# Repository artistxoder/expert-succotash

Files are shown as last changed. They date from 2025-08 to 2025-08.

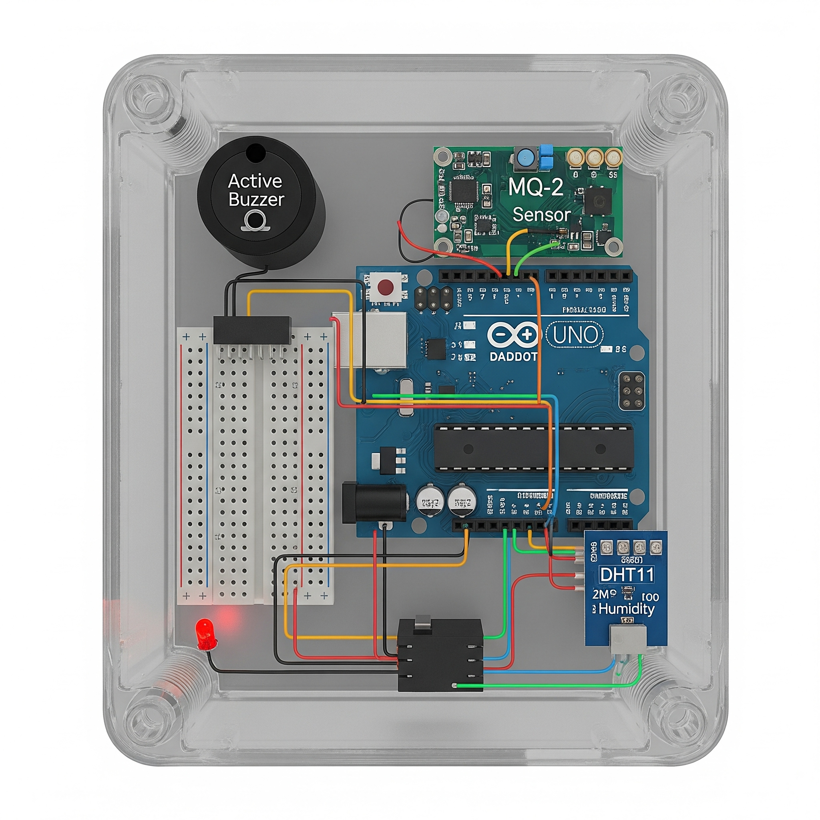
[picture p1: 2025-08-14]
wiring.png

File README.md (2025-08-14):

# Arduino MQ-2 Gas + DHT11 Temp/Humidity Monitor with 3D Printed Case and OLED Display

A combined gas detection and climate monitoring project using Arduino UNO, MQ-2 gas sensor, and DHT11 temperature/humidity sensor. This project includes a **100% screw-free 3D printable case** designed for easy assembly and optimal component integration, complete with buzzer and LED alarms, and **an integrated OLED display** for real-time data.

## Acknowledgements

Gemini, ChatGPT, and Claude were used to generate, refine, and improve the OpenSCAD code, making it more modular and parametric. The conceptual wiring diagram was also created with the assistance of these AI models.

## 📦 Features

* Detects gas/smoke using `MQ-2` sensor.
* Measures temperature and humidity with `DHT11`.
* Buzzer + LED alerts when gas exceeds a set threshold.
* Option to display temperature in Celsius or Fahrenheit.
* Smoothed gas readings for better accuracy.
* **Real-time data displayed on a 0.96" OLED screen.**
* **Custom 3D Printed Enclosure:** A two-part case (main body + lid) with integrated mounts for all components, including the OLED.
* **100% Screw-Free Design:** All components are held in place with snap-fits and friction mounts.

## 🛠 Hardware Required

* Arduino UNO (or compatible)
* MQ-2 Gas Sensor
* DHT11 Temperature/Humidity Sensor
* **0.96" OLED Display (I2C compatible, 128x64 pixels)**
* Active Buzzer
* LED + Resistor (220Ω)
* Jumper Wires
* Mini Breadboard (recommended for prototyping, mounts directly into case)

## 📐 Circuit Diagram

| Arduino Pin | Component |
| :--- | :--- |
| A0 | MQ-2 Analog Output |
| 3 | DHT11 Data Pin |
| 8 | Buzzer (+) |
| 9 | LED (+ via resistor) |
| SDA (A4) | OLED Data (SDA) |
| SCL (A5) | OLED Clock (SCL) |
| GND | All Components GND (including OLED) |
| 5V | MQ-2 + DHT11 + OLED VCC |

**Note:** The OLED display typically uses I2C communication, connecting to Arduino's Analog Pin 4 (SDA) and Analog Pin 5 (SCL).

## 📄 How It Works

1.  `MQ-2` detects gas concentration.
2.  `DHT11` reads temperature and humidity.
3.  Values are printed to the Serial Monitor **and displayed on the OLED screen**.
4.  If gas exceeds the set threshold, the buzzer sounds and the LED turns on.

## 🔧 Setup Instructions

1.  **Install the `DHT sensor library` in Arduino IDE:**
    * Go to `Sketch > Include Library > Manage Libraries...`
    * Search for `DHT sensor library by Adafruit` and install.
2.  **Install OLED display libraries in Arduino IDE:**
    * Go to `Sketch > Include Library > Manage Libraries...`
    * Search for `Adafruit SSD1306` and install it.
    * Search for `Adafruit GFX Library` and install it (required by SSD1306).
3.  Connect components according to the wiring diagram.
4.  Upload the code from `mq2_dht11.ino` to your Arduino.
5.  Open Serial Monitor (9600 baud) to view live data.

## 🖨️ 3D Printable Case

This project includes a custom 3D printed case designed to house all the components neatly. The design is optimized for smaller FDM 3D printers, specifically the **EasyThreed K7 Mini (100x100x100mm build volume)**, and includes a precise cutout for the OLED display.

### **Available Files:**

* **`STL/case_main.stl`**: The main body of the enclosure.
* **`STL/case_lid.stl`**: The snap-fit lid.

### **Printing Tips for K7 Mini (and similar small FDM printers):**

* **Printer Compatibility:** Designed for **100x100x100mm** print beds. The `case_width` in the OpenSCAD file has been adjusted to `98mm` to fit your K7 Mini perfectly with a small margin.
* **Layer Height:** Use `0.2mm` layer height for a good balance of detail and print time.
* **Filament:** `PLA` is recommended. The original design was optimized for Red PLA.
* **Supports:** The case is designed to be printed **without supports**. Verify this in your slicer.
* **Infill:** `15-20%` infill (e.g., Grid or Gyroid pattern) is generally sufficient.
* **Bed Adhesion:** Due to the K7 Mini typically not having a heated bed, strong bed adhesion is crucial to prevent warping, especially for the main case body. Consider using a `glue stick`, `blue painter's tape`, or `hair spray` on your print bed.
* **Temperatures:** Refer to your filament manufacturer's recommendations. A common starting point for PLA is `200-210°C` for the nozzle.

### **Assembly:**

1.  Print both `case_main.stl` and `case_lid.stl` separately.
2.  The Arduino mounts via snap-fit posts inside the main case.
3.  The mini breadboard slides into a friction-fit mount.
4.  Sensors (MQ-2, DHT11), outputs (Buzzer, LED), **and the OLED display** have dedicated slots and mounts.
5.  Route wires through the internal management channels.
6.  Once all components are installed and wired, the lid snaps securely onto the main case.

## 📐 CAD Source Files

The `.scad` file (`CAD/case.scad`) contains the full parametric design of the enclosure. You can open and modify this file using **OpenSCAD** (available for free at [openscad.org](https://openscad.org)).

* **Parametric Design:** The design is highly parametric. You can easily adjust dimensions like `tolerance`, `wall_thickness`, or reposition components by editing variables at the top of the `.scad` file.
* **Tolerance Adjustment:** If the snap-fit or friction-fit parts are too tight or too loose after printing, adjust the `tolerance` variable in the `.scad` file. Increase it for looser fits, decrease for tighter fits.
* **Why No G-code?** G-code is highly specific to a particular 3D printer model, its firmware, nozzle size, and even the exact filament type. Providing G-code would limit the project's usability to only those with identical setups. By providing the `.scad` and `.stl` files, you can generate optimized G-code for your specific printer and settings using your preferred slicer software (e.g., Cura, PrusaSlicer).

## ⚖ License

This project is licensed under the MIT License — you are free to use, modify, and distribute.

## 🤝 Contributing

Pull requests are welcome. For major changes or new features, please open an issue first to discuss ideas and potential implementations.

## 📢 Author

Created by Garrett Goben – inspired by DIY electronics and IoT safety devices.

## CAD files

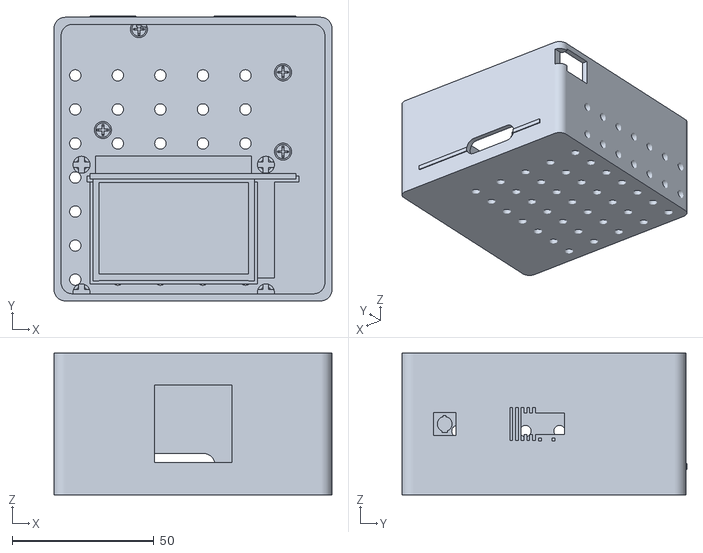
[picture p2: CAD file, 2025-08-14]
case.stl
98.0 x 100.4 x 50.0

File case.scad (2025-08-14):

// ============================================================================
// RED ARDUINO GAS DETECTION + CLIMATE MONITORING CASE - K7 MINI OPTIMIZED
// ============================================================================
// For: Arduino Uno + MQ-2 Gas Sensor + DHT11 Temp/Humidity + Buzzer + LED + OLED + Button
// Features: Gas detection alarm system with climate monitoring
// 100% SCREW-FREE DESIGN - Snap-fits and friction mounts only!
// Optimized for K7 Mini 3D Printer - Red PLA Filament
// ============================================================================

// Print quality optimization
$fn = 60; // Smooth curves for K7 Mini

// Global manufacturing tolerance for friction fits and clearances
tolerance = 0.2; // mm

// Small epsilon value to ensure clean cuts and avoid co-planar faces
// This is critical for manifold geometry for clean STL exports.
epsilon = 0.001; // mm

// --- RENDER CONTROL: Set ONLY ONE to 'true' at a time for printing ---
// To print the main case: Set RENDER_MAIN_CASE = true; RENDER_LID = false;
// To print the lid: Set RENDER_MAIN_CASE = false; RENDER_LID = true;
RENDER_MAIN_CASE = true;  // Set to true to render the main case
RENDER_LID       = false; // Set to true to render the lid

// ============================================================================
// COMPONENT SPECIFICATIONS
// ============================================================================

// Arduino Uno dimensions
arduino_width = 68.6; 	// mm
arduino_depth = 53.4; 	// mm
arduino_height = 1.6; 	// mm

// 0.96" OLED Display (128x64 pixels)
oled_width = 27.0; 		// mm
oled_height = 27.0; 		// mm 
oled_thickness = 4.0; 	// mm including PCB
oled_screen_width = 21.7; // mm (actual display area)
oled_screen_height = 11.2; // mm

// MQ-2 Gas Sensor (main detection component)
mq2_diameter = 20.0; 	// mm (sensor housing)
mq2_height = 16.0; 		// mm
mq2_pcb_width = 32.0; 	// mm (PCB dimensions)
mq2_pcb_depth = 20.0; 	// mm

// DHT11 Temperature/Humidity Sensor 
dht11_width = 16.0; 	// mm
dht11_depth = 12.0; 	// mm
dht11_height = 5.5; 	// mm

// Active Buzzer (alarm component)
buzzer_diameter = 12.0; // mm (typical active buzzer)
buzzer_height = 9.0; 	// mm

// LED + Resistor (visual alarm)
led_diameter = 5.0; 	// mm (standard LED)
led_height = 8.0; 		// mm
resistor_length = 6.0; 	// mm (220Ω resistor)

// Mini breadboard (for connections)
breadboard_width = 55; 	// mm
breadboard_depth = 35; 	// mm
breadboard_height = 8.5; // mm

// Button dimensions (for a common 6x6mm tact switch)
button_hole_diameter = 6.5; // Diameter of the round hole in the case top for the button plunger
button_pcb_width = 6.0;   // Width of the button's PCB
button_pcb_depth = 6.0;   // Depth of the button's PCB
button_pcb_thickness = 1.5;  // Thickness of the button's PCB
button_housing_clearance = 5.0; // Clearance needed below PCB for button housing/pins

// Case dimensions (K7 Mini bed optimized)
case_width = 98; 		// mm (Reduced from 130mm to fit 100mm bed with margin)
case_depth = 100; 		// mm (Fits 100mm bed)
case_height = 50; 		// mm (Fits 100mm bed)
wall_thickness = 2.5; 	// mm (perfect for 0.4mm nozzle)
corner_radius = 4; 		// mm

// ============================================================================
// COMPONENT POSITIONS
// ============================================================================

// Arduino mounting holes (standard Uno pattern)
arduino_hole_offsets = [
	[2.54, 15.24], 	// mm from board's bottom-left corner
	[15.24, 50.8],
	[66.04, 35.56],
	[66.04, 7.62]
];

// Arduino base offset within the case
arduino_base_offset_x = (case_width - arduino_width) / 2; // Centered
arduino_base_offset_y = 45; 	// mm from case edge (room for breadboard)

// OLED position (for front panel of main case)
oled_pos_x = (case_width / 2) - (oled_width / 2); // Centered horizontally on the front face
oled_pos_y = -wall_thickness;                   // On front face (Y-axis), to cut through the wall
oled_pos_z = case_height/2;                     // Centered vertically on case height

// Breadboard area (front of Arduino for connections)
breadboard_pos_x = arduino_base_offset_x; // Retained relative positioning
breadboard_pos_y = 8; 	// mm from case front edge (Y-axis)

// MQ-2 Gas Sensor (Pin A0) - CRITICAL: Needs maximum air exposure
mq2_pos_x = breadboard_pos_x + 25; // Relative to breadboard, fine for new width
mq2_pos_y = breadboard_pos_y + 15;
mq2_pos_z = case_height - wall_thickness; // Top mount for best gas detection

// DHT11 Sensor (Pin 3) - Side mount for ambient air readings
dht11_pos_x = case_width - wall_thickness; // Right side wall (auto-adjusts with case_width)
dht11_pos_y = case_depth/2; // Centered vertically on side
dht11_pos_z = case_height/2; // Centered horizontally on side

// Buzzer (Pin 8) - Top front for maximum sound output
buzzer_pos_x = case_width/4; // Adjusted to new case_width
buzzer_pos_y = 15;
buzzer_pos_z = case_height - wall_thickness; // On top face

// LED (Pin 9) - Front panel for visibility
led_pos_x = 15; // From left edge (X-axis), keeping 15mm offset
led_pos_y = -wall_thickness; // On front face (Y-axis)
led_pos_z = case_height/2; // Centered vertically

// Button position - on top, towards the front, centered
button_pos_x = case_width / 2;
button_pos_y = wall_thickness + 12; // A bit from the front edge
button_pos_z_top_surface = case_height - wall_thickness; // Z-coordinate of the top surface of the case

// ============================================================================
// REUSABLE GEOMETRIC PRIMITIVES
// ============================================================================

// Module to create a rounded box with consistent corners
module rounded_box(w, d, h, r) {
	hull() {
		translate([r, r, 0]) cylinder(r=r, h=h);
		translate([w-r, r, 0]) cylinder(r=r, h=h);
		translate([r, d-r, 0]) cylinder(r=r, h=h);
		translate([w-r, d-r, 0]) cylinder(r=r, h=h);
	}
}

// Protective mesh pattern (reusable module)
module protective_mesh(spacing, hole_d, radius_limit) {
	for(i = [-3:3]) {
		for(j = [-3:3]) {
			if(sqrt(i*i + j*j) <= radius_limit) {
				translate([i*spacing, j*spacing, 0])
					cylinder(d=hole_d, h=wall_thickness + 2 + epsilon, center=true); // Ensure deep cut
			}
		}
	}
}

// ============================================================================
// MAIN CASE BODY STRUCTURE
// ============================================================================

module main_case_structure() {
	difference() {
		// Outer shell with rounded corners
		rounded_box(case_width, case_depth, case_height, corner_radius);
		
		// Inner cavity, offset by wall thickness
		translate([wall_thickness, wall_thickness, wall_thickness])
			rounded_box(case_width - 2*wall_thickness, case_depth - 2*wall_thickness, case_height, corner_radius);
	}
}

// ============================================================================
// SNAP-FIT ARDUINO MOUNT (NO SCREWS!)
// ============================================================================

// Reusable snap-fit post module
module snap_fit_post(d_post, d_hole, h_post, d_clip, h_clip) {
	difference() {
		cylinder(d=d_post, h=h_post);
		// Center hole for Arduino mounting hole - ensure deep cut
		cylinder(d=d_hole + tolerance, h=h_post + 1 + epsilon); 
	}
	// Snap-fit top with flexible tabs
	translate([0, 0, h_post]) {
		difference() {
			cylinder(d=d_clip, h=h_clip);
			// Cross slots for flexibility - ensure deep cut
			translate([-d_clip/2 + 0.5, -0.3, -0.5 - epsilon])
				cube([d_clip - 1, 0.6, h_clip + 1 + 2*epsilon]);
			translate([-0.3, -d_clip/2 + 0.5, -0.5 - epsilon])
				cube([0.6, d_clip - 1, h_clip + 1 + 2*epsilon]);
		}
	}
}

module arduino_mounting() {
	mount_height = 8; 	// mm standoff height
	
	// Snap-fit Arduino mounting posts
	for(hole = arduino_hole_offsets) {
		translate([arduino_base_offset_x + hole[0], arduino_base_offset_y + hole[1], wall_thickness]) {
			snap_fit_post(
				d_post=6, 
				d_hole=2.8, 
				h_post=mount_height, 
				d_clip=5, 
				h_clip=2
			);
		}
	}
	
	// Arduino support ledges
	translate([arduino_base_offset_x - 2, arduino_base_offset_y - 2, wall_thickness + mount_height - 1.5])
		cube([arduino_width + 4, 2, 2]);
	
	translate([arduino_base_offset_x - 2, arduino_base_offset_y + arduino_depth, wall_thickness + mount_height - 1.5])
		cube([arduino_width + 4, 2, 2]);
	
	// Wire routing channel under Arduino
	translate([arduino_base_offset_x - 3, arduino_base_offset_y - 3, wall_thickness])
		cube([arduino_width + 6, 2, 3]);
}

// ============================================================================
// FRICTION-FIT BREADBOARD MOUNT
// ============================================================================
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

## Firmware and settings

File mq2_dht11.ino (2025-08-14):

#include <DHT.h>           // DHT sensor library
#include <Wire.h>          // Required for I2C communication (OLED)
#include <Adafruit_GFX.h>  // Core graphics library (OLED)
#include <Adafruit_SSD1306.h> // OLED display driver

// --- DHT11 Sensor Definitions ---
#define DHTPIN 3           // DHT11 data pin connected to Arduino pin 3
#define DHTTYPE DHT11      // Sensor type: DHT11

// Create DHT object
DHT dht(DHTPIN, DHTTYPE);

// --- MQ-2 Gas Sensor Definition ---
#define MQ2_PIN A0         // MQ-2 Analog output pin connected to Arduino pin A0

// --- Buzzer and LED Pins ---
#define BUZZER_PIN 8       // Buzzer (+) pin connected to Arduino pin 8
#define LED_PIN 9          // LED (+) pin connected to Arduino pin 9

// --- Mode Button Pin ---
#define MODE_BUTTON_PIN 2  // New: Mode button connected to digital pin 2

// --- OLED Display Definitions ---
#define SCREEN_WIDTH 128   // OLED display width, in pixels
#define SCREEN_HEIGHT 64   // OLED display height, in pixels
#define OLED_RESET -1      // Reset pin # (or -1 if sharing Arduino reset pin)

// Create the SSD1306 display object
// The address depends on your specific OLED module. Common addresses are 0x3C or 0x3D.
// You might need to change this if your display doesn't work.
Adafruit_SSD1306 display(SCREEN_WIDTH, SCREEN_HEIGHT, &Wire, OLED_RESET);

// --- System Thresholds and Settings ---
int gasThreshold = 300;    // Gas threshold value (adjust higher = less sensitive, lower = more sensitive)
bool useFahrenheit = true; // Temperature scale: true = Fahrenheit, false = Celsius
bool buttonState = LOW;    // Current state of the button
bool lastButtonState = LOW;// Previous state of the button
unsigned long lastDebounceTime = 0; // Last time the button input pin was toggled
unsigned long debounceDelay = 50;   // Debounce time; increase if button bounces

void setup() {
  // Initialize Serial communication for debugging
  Serial.begin(9600);

  // Initialize DHT sensor
  dht.begin();
  
  // Initialize OLED display (address 0x3C or 0x3D)
  // ssd1306_128_64 is the resolution. Check your display.
  if(!display.begin(SSD1306_SWITCHCAPVCC, 0x3C)) { 
    Serial.println(F("SSD1306 allocation failed"));
    for(;;); // Don't proceed, loop forever
  }

  // Clear the display buffer.
  display.clearDisplay();
  // Set text size to 1 (smallest)
  display.setTextSize(1);
  // Set text color to white
  display.setTextColor(SSD1306_WHITE);
  // Set cursor to (0,0) (top-left corner)
  display.setCursor(0,0);
  // Print welcome message to OLED
  display.println(F("System Initializing..."));
  display.display(); // Show the splashscreen buffer on the display

  // Pin mode setup
  pinMode(MQ2_PIN, INPUT);
  pinMode(BUZZER_PIN, OUTPUT);
  pinMode(LED_PIN, OUTPUT);
  pinMode(MODE_BUTTON_PIN, INPUT_PULLUP); // Use INPUT_PULLUP for button to avoid external resistor

  // Initial warming up for MQ-2 sensor (crucial for accurate readings)
  Serial.println("Warming up MQ-2 sensor for 20 seconds...");
  display.setCursor(0, 10);
  display.println(F("MQ-2 Warming up..."));
  display.display();
  delay(20000); 
  Serial.println("System Ready!");
  display.clearDisplay();
  display.setCursor(0,0);
  display.println(F("System Ready!"));
  display.display();
  delay(1000); // Display "System Ready!" for a moment
}

void loop() {
  // --- Handle Button Press ---
  int reading = digitalRead(MODE_BUTTON_PIN);

  // If the button state has changed (and debounced)
  if (reading != lastButtonState) {
    lastDebounceTime = millis();
  }

  if ((millis() - lastDebounceTime) > debounceDelay) {
    // If the button state is LOW (pressed, due to INPUT_PULLUP)
    if (reading != buttonState) {
      buttonState = reading;
      if (buttonState == LOW) { // Button is pressed
        useFahrenheit = !useFahrenheit; // Toggle temperature scale
      }
    }
  }
  lastButtonState = reading; // Save the reading for the next loop iteration

  // Clear the display for new readings
  display.clearDisplay();

  // --- Read MQ-2 Sensor ---
  // Smooth gas reading by averaging 5 samples to reduce noise
  long totalGas = 0;
  for (int i = 0; i < 5; i++) {
    totalGas += analogRead(MQ2_PIN);
    delay(10); // Small delay between readings
  }
  int gasValue = totalGas / 5;

  // --- Read DHT11 Sensor ---
  float humidity = dht.readHumidity();
  // Read temperature based on the 'useFahrenheit' setting
  float temperature = useFahrenheit ? dht.readTemperature(true) : dht.readTemperature();

  // Check if any DHT sensor reading failed
  if (isnan(humidity) || isnan(temperature)) {
    Serial.println("Error: Failed to read from DHT11 sensor!");
    display.setCursor(0,0);
    display.println(F("DHT11 Error!"));
    display.display();
    delay(2000); // Display error for 2 seconds
    return; // Skip the rest of the loop if sensor read fails
  }

  // --- Display Readings on Serial Monitor ---
  Serial.print("Gas: "); Serial.print(gasValue);
  Serial.print(" | Humidity: "); Serial.print(humidity); Serial.print("%");
  Serial.print(" | Temp: "); Serial.print(temperature);
  Serial.println(useFahrenheit ? "°F" : "°C");

  // --- Display Readings on OLED ---
  // Display Gas Value
  display.setTextSize(2); // Larger text for main readings
  display.setCursor(0,0);
  display.print(F("Gas: "));
  display.println(gasValue);

  // Display Temperature
  display.setCursor(0, 24); // Move cursor down for next line
  display.print(F("Temp: "));
  display.print(temperature);
  display.print(useFahrenheit ? (char)247 : " "); // Degree symbol (char 247 for some fonts) or space
  display.println(useFahrenheit ? "F" : "C");

  // Display Humidity
  display.setCursor(0, 48); // Move cursor down again
  display.print(F("Hum: "));
  display.print(humidity);
  display.println(F("%"));

  // Show the updated buffer on the display
  display.display();

  // --- Gas Alarm Trigger ---
  if (gasValue > gasThreshold) {
    digitalWrite(BUZZER_PIN, HIGH); // Turn buzzer ON
    digitalWrite(LED_PIN, HIGH);    // Turn LED ON
    Serial.println("!!! GAS DETECTED !!!");
    // Optionally, display alarm on OLED if space allows or in a separate screen
    // display.setCursor(0,0); display.println("GAS ALARM!"); display.display();
  } else {
    digitalWrite(BUZZER_PIN, LOW);  // Turn buzzer OFF
    digitalWrite(LED_PIN, LOW);     // Turn LED OFF
  }

  delay(1000); // Wait for 1 second before next reading
}
